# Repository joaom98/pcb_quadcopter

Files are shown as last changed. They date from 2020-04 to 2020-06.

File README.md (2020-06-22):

# pcb_quadcopter
An open-source PCB multirotor project, development in progress.
The intent is to make an affordable, simple and customizable quadcopter that can be built and used by anyone. 

## Inspiration

So, I have seen some interesting projects online and decided to try developing a variation. Here are some of the references that inspired me into making my own:

* [Arduino PCB quadcopter - ElecttoNOOBS](https://www.youtube.com/watch?v=J0x4ChjUS00)
* [ArduBee, a Ready-To-Fly Micro drone for Education and Swarming](https://discuss.ardupilot.org/t/ardubee-a-ready-to-fly-micro-drone-for-education-and-swarming/54362)
* [Microhawk at Outcast Dronework - Rotor Riot](https://www.youtube.com/watch?v=aRctXEhmRdY)
* [MultiWii](http://www.multiwii.com/)
* [OpenFC Open Hardware Flight Controller - DroneMesh](https://www.youtube.com/playlist?list=PLoPtpxJIxgnYnPrOeGHs3rdhhPgNGIYN5)
* [FeatherWing quadcopter](https://hackaday.io/project/168441-quadcopter-featherwing-for-huzzah32)

## Specifications

Here are some of the specifications that I want to follow for this project. They are open to changes:

* PCB Frame containing all of the electronics and components
* STM32 microcontroller able to run BetaFlight
* 7mm brushed motors
* 2" Propellers
* Micro RF SBUS receiver
* 18650 Li-Ion batteries

## Future implementations/extras

Theese are some features that are cool but aren't included in the base project (yet, hopefully):

* FPV camera and VTX
* SD card for camera footage
* RPi 0 support
* Ardupilot support

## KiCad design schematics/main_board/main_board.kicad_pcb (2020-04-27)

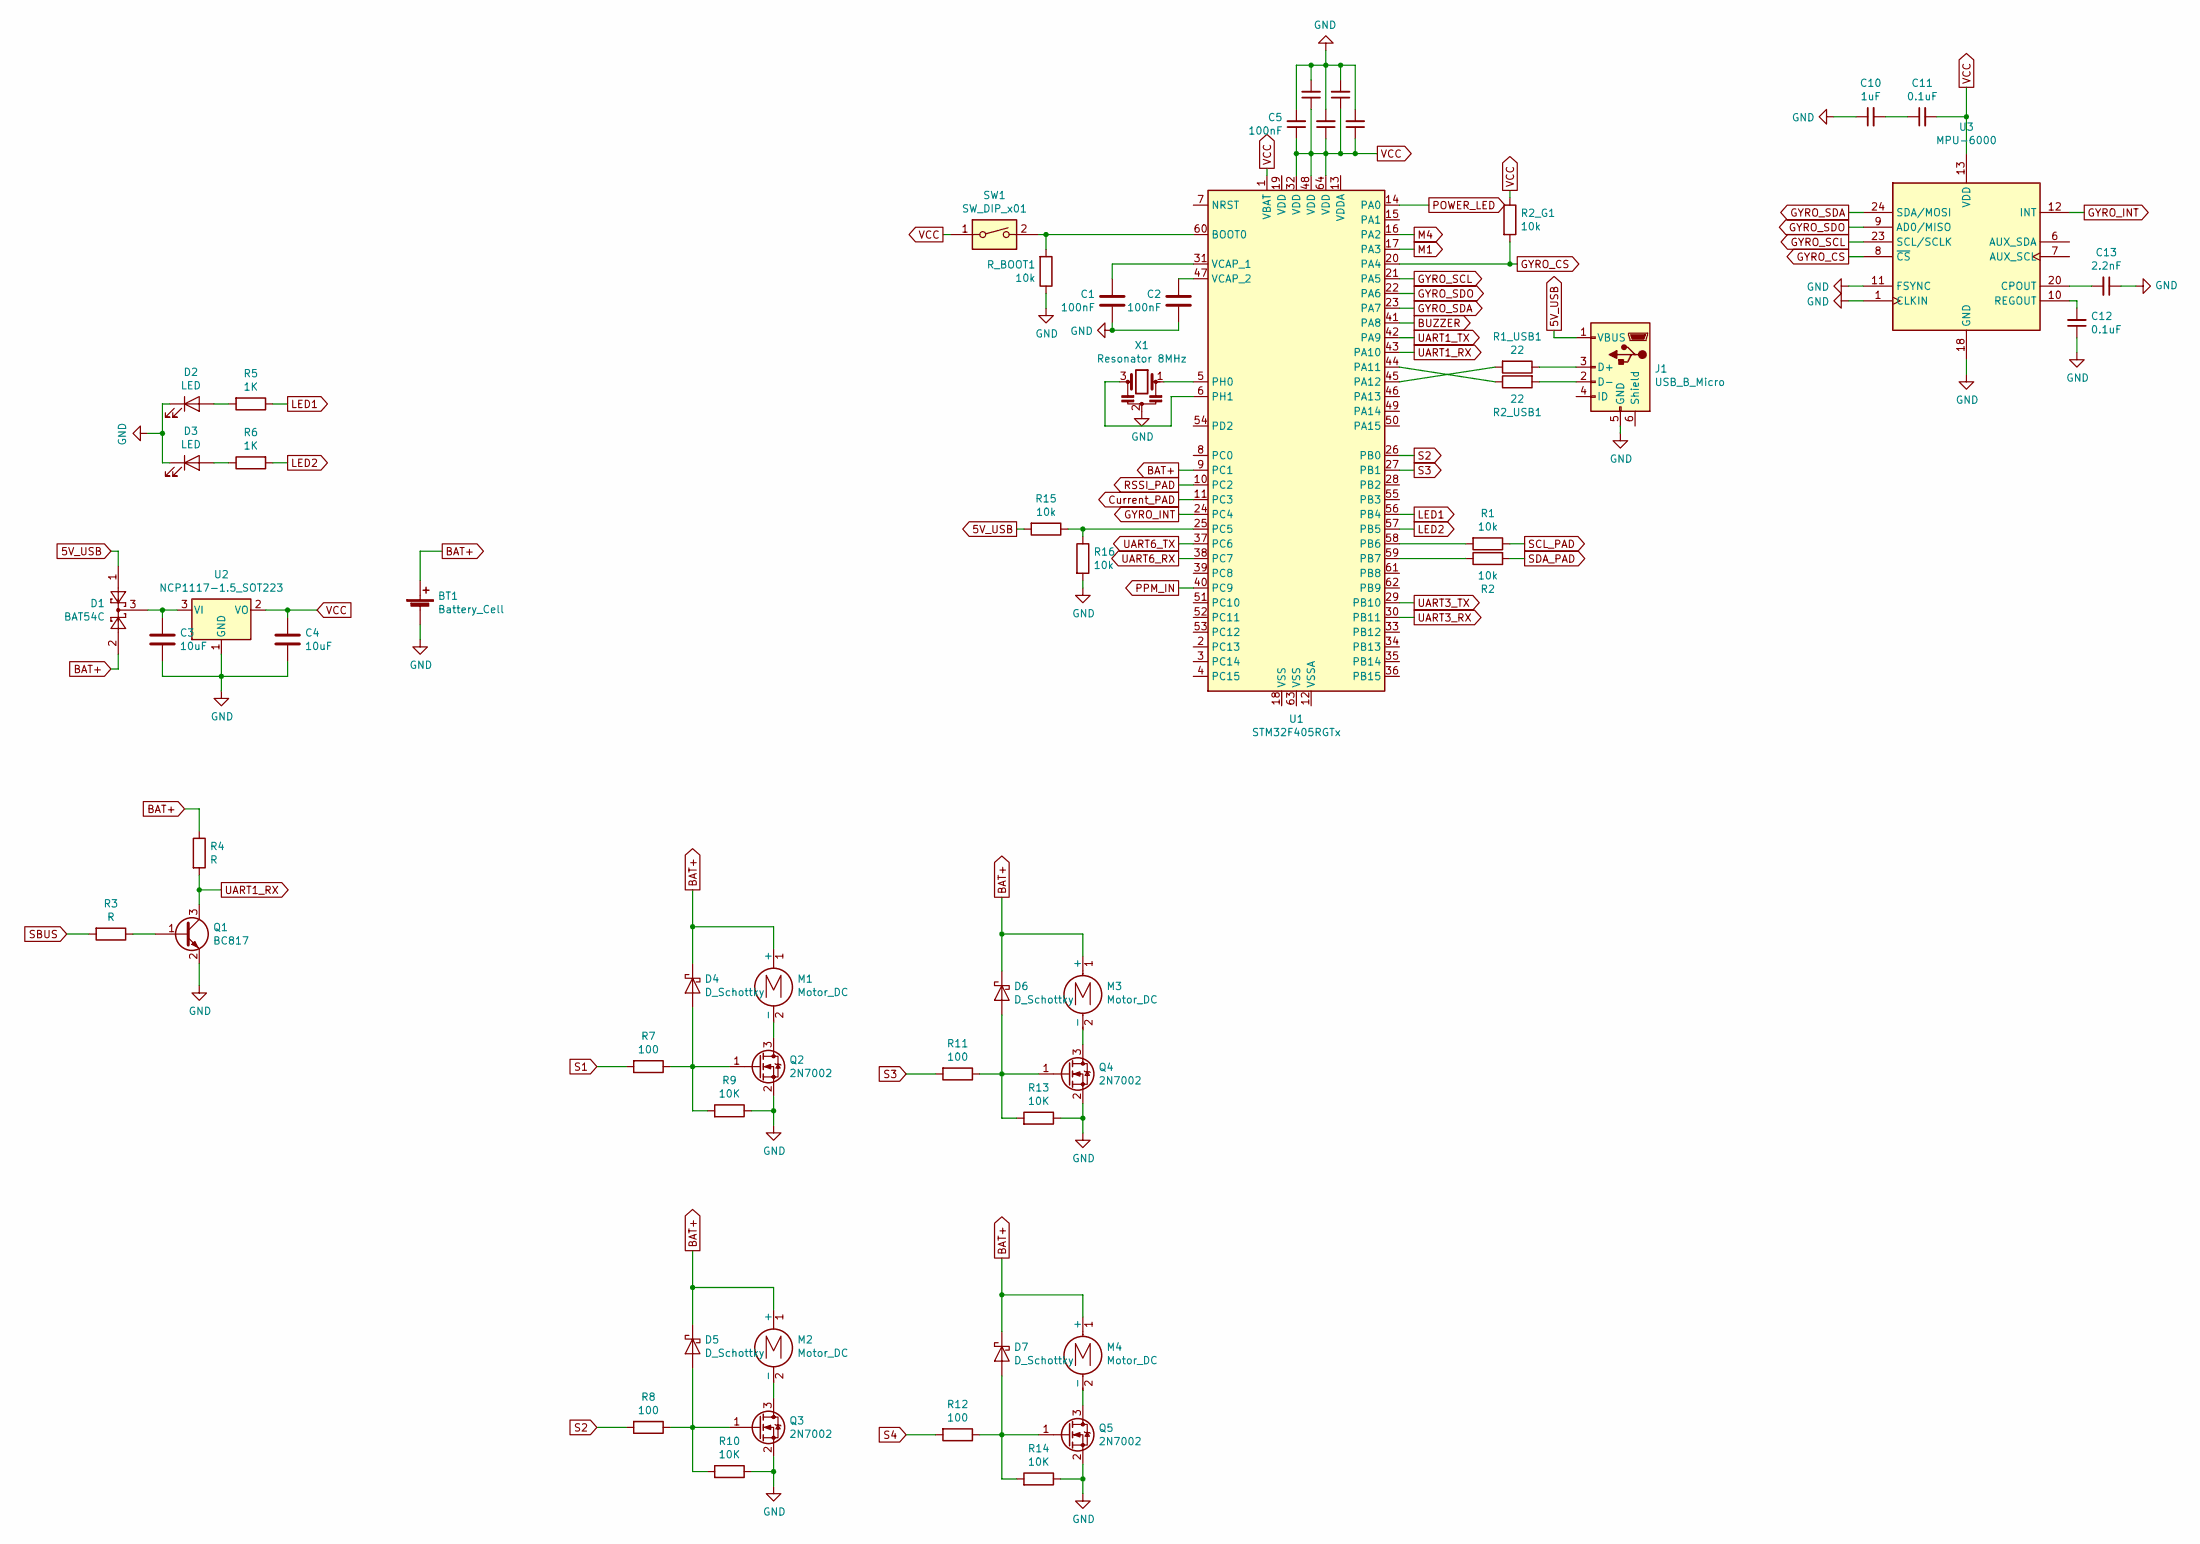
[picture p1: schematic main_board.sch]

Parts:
BT1: Battery_Cell; BatteryHolder_Keystone_1042_1x18650
C1, C2, C5, C6, C7, C8, C9: 100nF; C_0805_2012Metric
C3, C4: 10uF; C_0805_2012Metric
C10: 1uF; C_0805_2012Metric
C11, C12: 0.1uF; C_0805_2012Metric
C13: 2.2nF; C_0805_2012Metric
D1: BAT54C; D_SOT-23_ANK
D2, D3: LED; LED_0805_2012Metric
D4, D5, D6, D7: D_Schottky; D_0805_2012Metric
J1: USB_B_Micro; USB_Micro-B_Molex-105133-0031
M1, M2, M3, M4: Motor_DC; Buzzer_CUI_CPT-9019S-SMT
Q1: BC817; SOT-23
Q2, Q3, Q4, Q5: 2N7002; SOT-23
R1, R2, R2_G1, R15, R16: 10k; R_0402_1005Metric
R1_USB1, R2_USB1: 22; R_0402_1005Metric
R3, R4: R; R_0402_1005Metric
R5, R6: 1K; R_0402_1005Metric
R7, R8, R11, R12: 100; R_0402_1005Metric
R9, R10, R13, R14: 10K; R_0402_1005Metric
R_BOOT1: 10k; R_0402_1005Metric
SW1: SW_DIP_x01; SW_SPST_REED_CT05-XXXX-J1
U1: STM32F405RGTx; LQFP-64_10x10mm_P0.5mm
U2: NCP1117-1.5_SOT223; SOT-223-3_TabPin2
U3: MPU-6000; InvenSense_QFN-24_4x4mm_P0.5mm
X1: Resonator 8MHz; Resonator_SMD_muRata_CSTxExxV-3Pin_3.0x1.1mm_HandSoldering

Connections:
5V_USB: D1.1, J1.1 (VBUS), R15.2
BAT+: BT1.1 (+), D1.2, D4.1 (K), D5.1 (K), D6.1 (K), D7.1 (K), M1.1 (+), M2.1 (+), M3.1 (+), M4.1 (+), R4.1, U1.9 (PC1)
BUZZER: U1.41 (PA8)
Current_PAD: U1.11 (PC3)
GND: BT1.2 (-), C1.1, C2.1, C3.2, C4.2, C5.2, C6.2, C7.2, C8.2, C9.2, C10.1, C12.1, C13.1, D2.1 (K), D3.1 (K), J1.5 (GND), Q1.2 (E), Q2.2 (S), Q3.2 (S), Q4.2 (S), Q5.2 (S), R9.1, R10.1, R13.1, R14.1, R16.2, R_BOOT1.1, U2.1 (GND), U3.1 (CLKIN), U3.11 (FSYNC), U3.18 (GND), X1.2
GYRO_CS: R2_G1.2, U1.20 (PA4), U3.8 (~CS)
GYRO_INT: U1.24 (PC4), U3.12 (INT)
GYRO_SCL: U1.21 (PA5), U3.23 (SCL/SCLK)
GYRO_SDA: U1.23 (PA7), U3.24 (SDA/MOSI)
GYRO_SDO: U1.22 (PA6), U3.9 (AD0/MISO)
LED1: R5.1, U1.56 (PB4)
LED2: R6.2, U1.57 (PB5)
unnamed: C1.2, U1.31 (VCAP_1)
unnamed: C2.2, U1.47 (VCAP_2)
unnamed: C3.1, D1.3, U2.3 (VI)
unnamed: C10.2, C11.1
unnamed: C12.2, U3.10 (REGOUT)
unnamed: C13.2, U3.20 (CPOUT)
unnamed: D2.2 (A), R5.2
unnamed: D3.2 (A), R6.1
unnamed: D4.2 (A), Q2.1 (G), R7.1, R9.2
unnamed: D5.2 (A), Q3.1 (G), R8.1, R10.2
unnamed: D6.2 (A), Q4.1 (G), R11.1, R13.2
unnamed: D7.2 (A), Q5.1 (G), R12.1, R14.2
unnamed: J1.2 (D-), R2_USB1.2
unnamed: J1.3 (D+), R1_USB1.1
unnamed: M1.2 (-), Q2.3 (D)
unnamed: M2.2 (-), Q3.3 (D)
unnamed: M3.2 (-), Q4.3 (D)
unnamed: M4.2 (-), Q5.3 (D)
unnamed: Q1.1 (B), R3.1
unnamed: R1.2, U1.58 (PB6)
unnamed: R1_USB1.2, U1.45 (PA12)
unnamed: R2.1, U1.59 (PB7)
unnamed: R2_USB1.1, U1.44 (PA11)
unnamed: R15.1, R16.1, U1.25 (PC5)
unnamed: R_BOOT1.2, SW1.2, U1.60 (BOOT0)
unnamed: U1.5 (PH0), X1.1
unnamed: U1.6 (PH1), X1.3
POWER_LED: U1.14 (PA0)
PPM_IN: U1.40 (PC9)
RSSI_PAD: U1.10 (PC2)
S2: R8.2, U1.26 (PB0)
S3: R11.2, U1.27 (PB1)
SBUS: R3.2
SCL_PAD: R1.1
SDA_PAD: R2.2
UART1_RX: Q1.3 (C), R4.2, U1.43 (PA10)
UART1_TX: U1.42 (PA9)
UART3_RX: U1.30 (PB11)
UART3_TX: U1.29 (PB10)
UART6_RX: U1.38 (PC7)
UART6_TX: U1.37 (PC6)
VCC: C4.1, C5.1, C6.1, C7.1, C8.1, C9.1, C11.2, R2_G1.1, SW1.1, U1.1 (VBAT), U1.32 (VDD), U1.48 (VDD), U1.64 (VDD), U2.2 (VO), U3.13 (VDD)

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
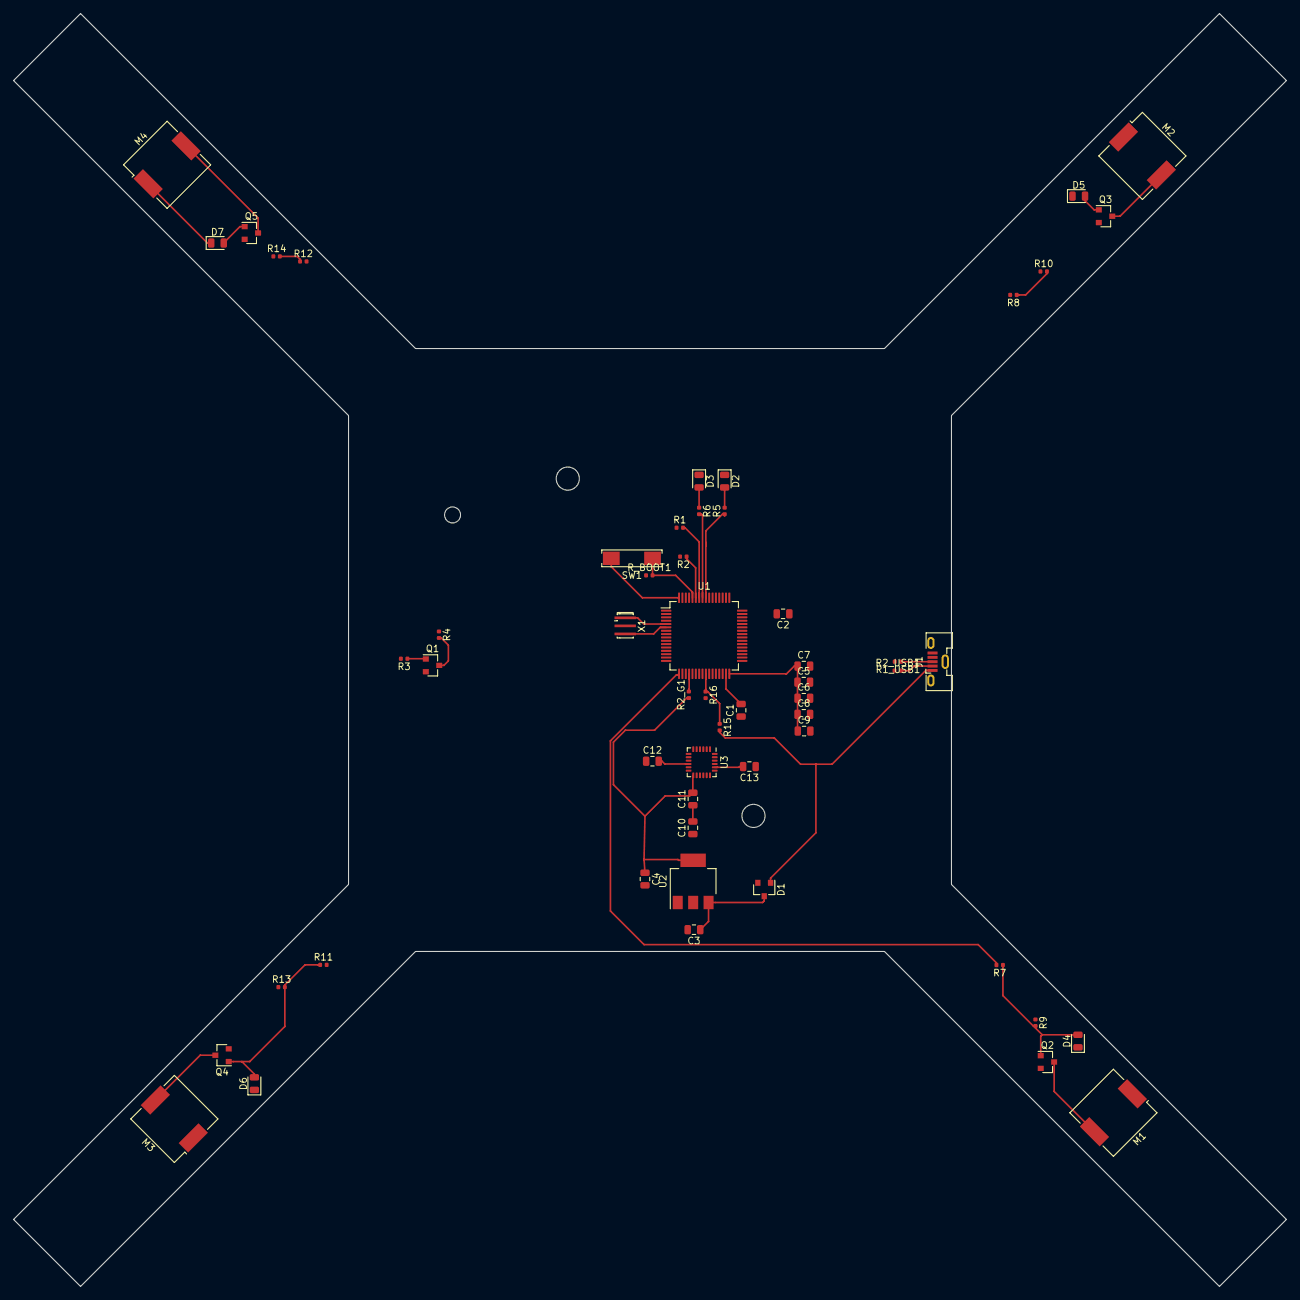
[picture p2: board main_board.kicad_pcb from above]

Board: 2 copper layers, 190.0 x 190.0 mm, 56 parts (1 on the bottom side), 43 nets.

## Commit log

2020-04-18 Folder with boards created
    [main_board.kicad_pcb, main_board.sch]
2020-04-18 Added main uC and Gyro schematics
    [main_board.sch]
2020-04-18 Saved changes
    [main_board.sch]
2020-04-19 Added motors, voltage regulator and LED's
    [main_board.sch]
2020-04-20 Created the PCB frame and added the components on top
    [main_board.sch]
2020-04-27 Changed some footprints, added some traces
    [main_board.kicad_pcb, main_board.sch]
2020-04-27 Fixed oscillator footprint and motor signal names
    [main_board.sch]
